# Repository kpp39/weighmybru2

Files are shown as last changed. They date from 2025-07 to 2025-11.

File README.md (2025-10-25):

<p align="center">
WeighMyBru Dashboard
</p>

<p align="center">  <b>The smart coffee scale that doesn't break the bank!<br>https://weighmybru.com</p>
<br>




This project is a smart coffee scale with a webserver hosted on the ESP32-S3.
This scale was designed to be used in conjunction with GaggiMate, but can also be used as a standalone scale. The project is still in a beta phase and is actively being worked on. Please head over to the [Discord](https://discord.gg/HYp4TSEjSf) server for more info. This scale was inspired by [EspressiScale](https://www.espressiscale.com) but with a non-custom PCB approach. The idea is to be low-cost, easily sourcable scale.

<br>
<br>
<p>
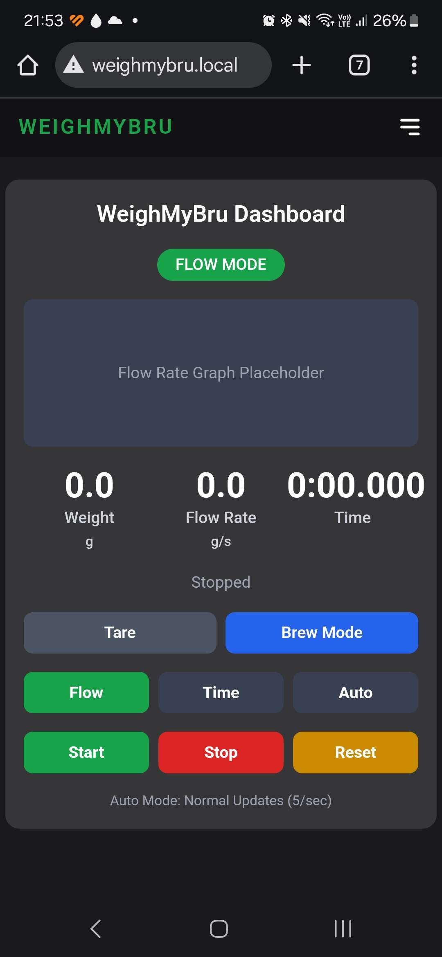
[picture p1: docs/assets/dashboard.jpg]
WeighMyBru Dashboard

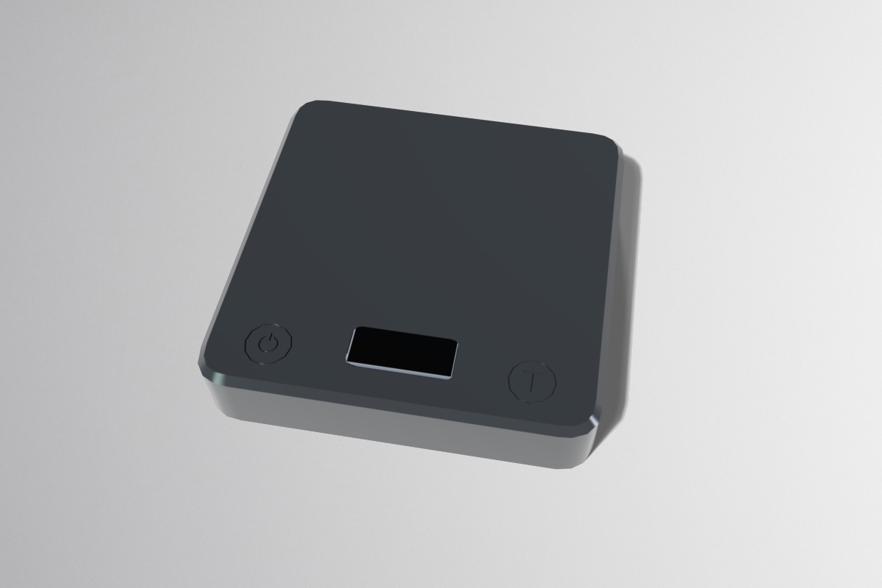
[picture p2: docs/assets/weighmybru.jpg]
WeighMyBru Dashboard

</p>

## Documentation

The documentation, build video guide, flashing software etc. can be found on the website. 

[WeighMyBru Guides](https://weighmybru.com/guides/)

## Features

- Webserver via WiFi
- Bluetooth connectivity to GaggiMate
- Calibration via webserver
- Real-time flowrate display
- Adjustable decimal point readings
- Different modes for to cater for espresso and pour-overs

## GaggiMate

GaggiMate now fully supports WeighMyBru scale.

[GaggiMate](https://github.com/jniebuhr/gaggimate)

## Installation

Installation instructions are currently under development, for now follow the [link](https://031devstudios.github.io/weighmybru-docs/#/installation/flashing) for step-by-step installation instructions. Additionally, a video is available on [YouTube](https://www.youtube.com/watch?v=O5SP40Liuq0)

```
  this project requires VSCode with PlatformIO extension installed
```
## Bill Of Materials (BOM)

| Qty | Item | Amazon Link | Aliexpress Link |
| --- | --- | ---| --- |
|  1  | 500g Mini Loadcell (I-shaped) | https://a.co/d/6kvxZ0H |  |
|  1  | HX711 | https://a.co/d/3KiYRkA |  |
|  1  | ESP32-S3-Supermini Board | https://a.co/d/6289vbS |  |
|  2  | Capacitive Tocuh Pads | https://a.co/d/014di6l |  |
|  1  | 0.91" SSD1306 OLED Display | https://a.co/d/9UClWku |  |
|  1  | 800mAh Li-ion Battery | https://a.co/d/gbr1Yft |  |
|  1  | JST-PH 2.0 Male Connector | https://a.co/d/3BZGuHW |  |
|  1  | Slide Switch | https://a.co/d/9KRqMyF |  |
|  1  | Hookup Wire (Various Colors) | https://a.co/d/1Fs8os9 |  |
|  2  | M3x5x4 Heat Set Inserts | https://a.co/d/bnQD7Iu |  |
|  16 | M1.7x4 Self Tapping Screws | https://a.co/d/1np5Nes |  |
|  4  | M3x12 Button Head Screws | https://a.co/d/iqM3d6E |  |
|  2  | 100K ohm 1% 1/4w resistors | https://a.co/d/3R0YmGM |  |
|  4  | Self-Adhesive Rubber Feet | https://a.co/d/0q9TRmR |  |
|  1  | Double Sided Tape (To hold Battery) | https://a.co/d/gM5SWwH |  |

## Printed Parts (Found in CAD Folder)

| Qty | Item | 
| --- | ---|
|  1  | Bottom* |  
|  1  | Top |
|  1  | ESP32 Clamp |
|  1  | Screen Clamp |
|  4  | M2 Washers (Used for HX711) |

\* Bottom has 2 options - The supported option has engineered supports, while the standard option requires you to slice with your own supports.

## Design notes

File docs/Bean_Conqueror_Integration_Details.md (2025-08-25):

# WeighMyBru - Bean Conqueror Integration Details

## Current BLE Implementation for Bean Conqueror Integration

### Advertising Information
- **Device Name**: `WeighMyBru`
- **Advertising**: Device advertises continuously when not connected

### Service and Characteristic UUIDs
- **Service UUID**: `6E400001-B5A3-F393-E0A9-E50E24DCCA9E`
- **GaggiMate Weight Characteristic UUID**: `6E400002-B5A3-F393-E0A9-E50E24DCCA9E`
  - Properties: READ, NOTIFY, INDICATE
  - Used for: GaggiMate weight data (WeighMyBru protocol format)
- **Command Characteristic UUID**: `6E400003-B5A3-F393-E0A9-E50E24DCCA9E`
  - Properties: WRITE, WRITE_NR, NOTIFY
  - Used for: Receiving commands from both apps (tare, timer control)
- **Bean Conqueror Weight Characteristic UUID**: `6E400004-B5A3-F393-E0A9-E50E24DCCA9E`
  - Properties: READ, NOTIFY, INDICATE
  - Used for: Bean Conqueror weight data (simple float format)

### Required API Functions - Implementation Status

#### ✅ Weight Send
- **Status**: ✅ IMPLEMENTED
- **Frequency**: 50ms interval (20 updates/second)
- **Format**: WeighMyBru protocol with weight data in grams
- **Precision**: Floating point weight values

#### ✅ Taring
- **Status**: ✅ IMPLEMENTED
- **Command Code**: `0x01`
- **Protocol**: Send `[0x03, 0x0A, 0x01, 0x01, 0x00]` to command characteristic
- **Response**: Confirmation message sent back via weight characteristic
- **Function**: Zeros the scale reading

#### ✅ Timer Start
- **Status**: ✅ IMPLEMENTED (NEW)
- **Command Code**: `0x02`
- **Protocol**: Send `[0x03, 0x0A, 0x02, 0x01, 0x00]` to command characteristic
- **Response**: Start confirmation `[0x03, 0x0A, 0x02, 0x01, 0x00]`
- **Function**: Starts the brewing timer on WeighMyBru scale

#### ✅ Timer Stop
- **Status**: ✅ IMPLEMENTED (NEW)
- **Command Code**: `0x03`
- **Protocol**: Send `[0x03, 0x0A, 0x03, 0x01, 0x00]` to command characteristic
- **Response**: Stop confirmation `[0x03, 0x0A, 0x03, 0x01, 0x00]`
- **Function**: Stops the brewing timer on WeighMyBru scale

#### ✅ Timer Reset
- **Status**: ✅ IMPLEMENTED (NEW)
- **Command Code**: `0x04`
- **Protocol**: Send `[0x03, 0x0A, 0x04, 0x01, 0x00]` to command characteristic
- **Response**: Reset confirmation `[0x03, 0x0A, 0x04, 0x01, 0x00]`
- **Function**: Resets the brewing timer to 0:00.000

## Protocol Details

### Command Message Format
```
[Product_ID, Message_Type, Command, Trigger, Reserved]
```
- **Product_ID**: `0x03` (WeighMyBru identifier)
- **Message_Type**: `0x0A` (System command)
- **Command**: Command code (0x01-0x04)
- **Trigger**: `0x01` (Execute command)
- **Reserved**: `0x00` (Future use)

### Weight Data Format
- Sent via weight characteristic notifications
- **Format**: Simple 4-byte float in little-endian byte order  
- **Data**: Weight value directly in grams (e.g., 15.67g)
- **Precision**: Full floating-point precision
- **Update Rate**: Automatic notifications every 50ms when connected
- **Byte Layout**: `[float32_little_endian]` (4 bytes total)

### Connection Behavior
- Automatically starts advertising when disconnected
- Stops advertising when connected
- Supports single client connection
- Automatic reconnection support

## Integration Notes for Bean Conqueror

1. **Discovery**: Look for device named "WeighMyBru" in BLE scan
2. **Connection**: Connect to service UUID `6E400001-B5A3-F393-E0A9-E50E24DCCA9E`
3. **Weight Subscription**: Subscribe to notifications on `6E400004-B5A3-F393-E0A9-E50E24DCCA9E` (Bean Conqueror specific)
4. **Command Sending**: Write commands to `6E400003-B5A3-F393-E0A9-E50E24DCCA9E`
5. **Timer Control**: All timer functions (start/stop/reset) are now available via BLE

### Important: Dual App Support
The WeighMyBru scale now supports **both Bean Conqueror and GaggiMate simultaneously**:

**Bean Conqueror**: 
- Weight data: `6E400004-...` (4-byte float32 little-endian)
- Expected format: Simple float value in grams

**GaggiMate**: 
- Weight data: `6E400002-...` (20-byte WeighMyBru protocol)
- Expected format: Full protocol with headers and checksums

**Commands**: Both apps share `6E400003-...` for tare and timer commands

## Technical Specifications

- **Platform**: ESP32-S3
- **BLE Stack**: ESP32 Arduino BLE library
- **Update Rate**: 20Hz (50ms intervals)
- **Weight Range**: 0-5000g (depending on load cell)
- **Precision**: 0.1g
- **Timer Precision**: Millisecond accuracy
- **Connection**: Single client BLE connection
- **Power**: Battery operated with monitoring

## Example Usage

```javascript
// Connect to WeighMyBru
const device = await navigator.bluetooth.requestDevice({
  filters: [{name: 'WeighMyBru'}],
  optionalServices: ['6E400001-B5A3-F393-E0A9-E50E24DCCA9E']
});

// Subscribe to weight notifications
const weightChar = await service.getCharacteristic('6E400002-B5A3-F393-E0A9-E50E24DCCA9E');
await weightChar.startNotifications();

// Send tare command
const commandChar = await service.getCharacteristic('6E400003-B5A3-F393-E0A9-E50E24DCCA9E');
await commandChar.writeValue(new Uint8Array([0x03, 0x0A, 0x01, 0x01, 0x00]));

// Send timer start command
await commandChar.writeValue(new Uint8Array([0x03, 0x0A, 0x02, 0x01, 0x00]));
```

## Changes Made for Bean Conqueror Integration

### New Features Added:
1. **Timer Control API**: Added BLE commands for start/stop/reset timer
2. **Command Processing**: Enhanced message processing to handle timer commands
3. **Display Integration**: Linked BLE timer commands to physical display timer
4. **Confirmation Messages**: Added response confirmations for all commands

### Files Modified:
- `include/BluetoothScale.h` - Added timer command enums and methods
- `src/BluetoothScale.cpp` - Implemented timer command handling
- `src/main.cpp` - Added display reference for timer control

All required API functions for Bean Conqueror integration are now implemented and ready for testing.

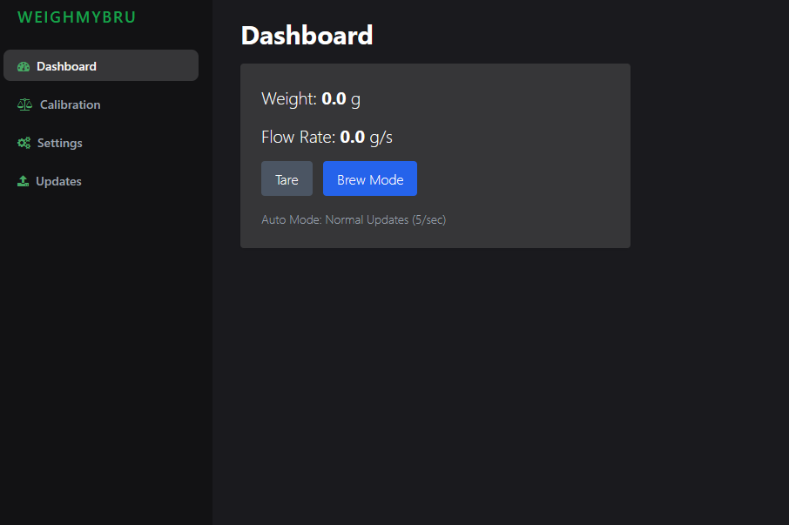
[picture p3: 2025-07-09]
docs/assets/dashboard.png

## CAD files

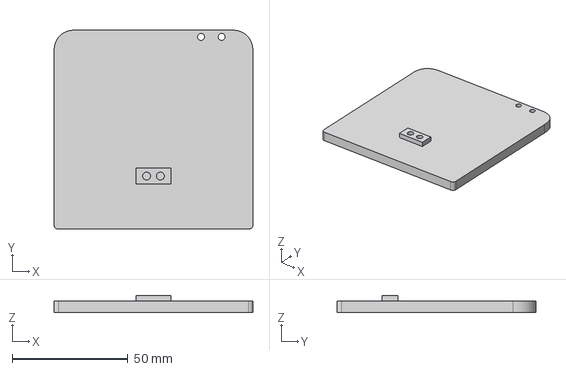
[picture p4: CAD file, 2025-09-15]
cad/step/WeighMyBru² - Bottom Supported.step
86.0 x 86.0 x 7.50 mm

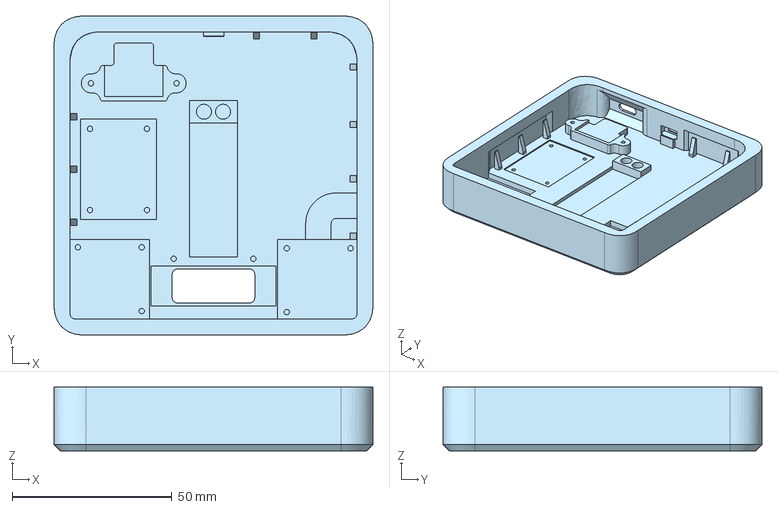
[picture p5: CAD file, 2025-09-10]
cad/step/WeighMyBru² - Top.step
100.0 x 100.0 x 20.0 mm

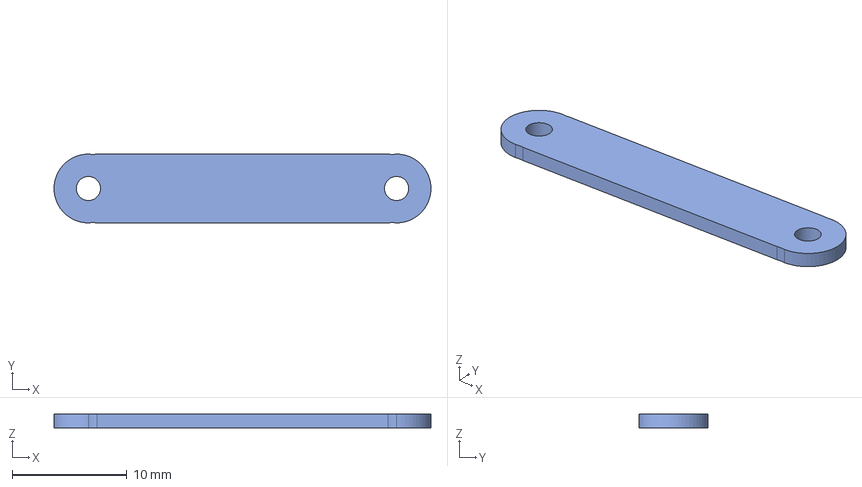
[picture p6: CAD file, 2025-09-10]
cad/step/WeighMyBru² - ESP32 Clamp.step
32.8 x 6.00 x 1.20 mm

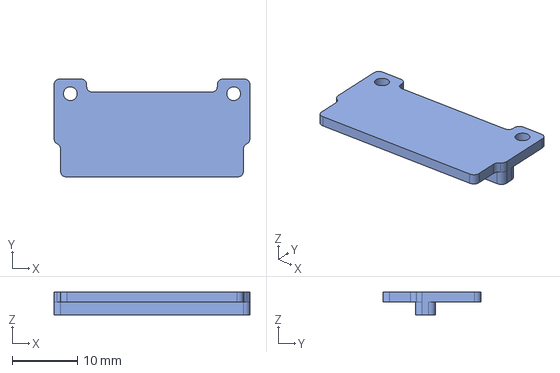
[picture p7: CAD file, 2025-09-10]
cad/step/WeighMyBru² - Screen Clamp.step
30.0 x 15.0 x 3.50 mm

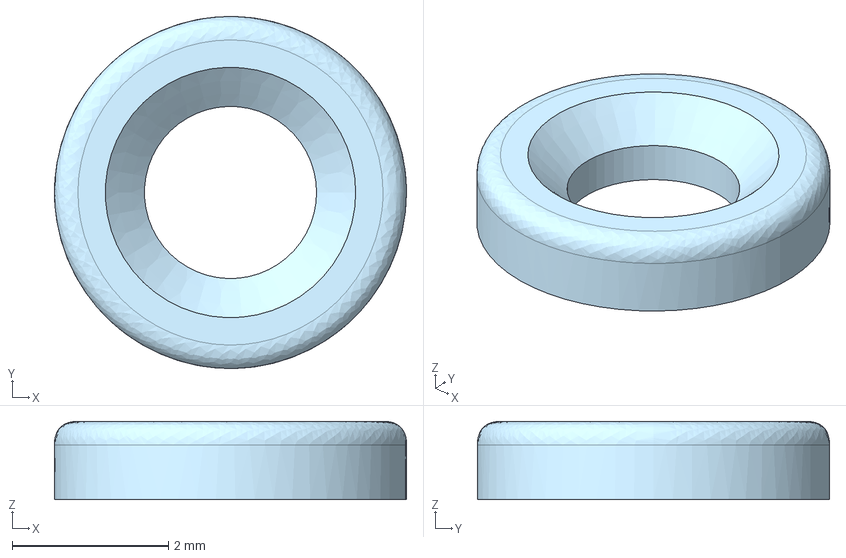
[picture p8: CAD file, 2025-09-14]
cad/step/WeighMyBru² - M2 Washer.step
4.50 x 4.50 x 1.00 mm

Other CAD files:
cad/step/WeighMyBru² - Bottom.step
cad/3mf/WeighMyBru² - Bottom Supported.3mf
cad/3mf/WeighMyBru² - Bottom.3mf
cad/3mf/WeighMyBru² - ESP32 Clamp.3mf
cad/3mf/WeighMyBru² - M2 Washer.3mf
cad/3mf/WeighMyBru² - Screen Clamp.3mf
cad/3mf/WeighMyBru² - Top.3mf

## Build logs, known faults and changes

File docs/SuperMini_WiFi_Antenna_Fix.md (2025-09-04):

# ESP32-S3 SuperMini WiFi Antenna Fix

## Problem Description

Some ESP32-S3 SuperMini development boards have a hardware design issue where:
- WiFi only works when physically touching the antenna
- Poor WiFi connectivity or complete failure to connect
- Issues are more pronounced at distance from the router

## Root Cause

The issue is caused by:
1. **Poor antenna design** - inadequate antenna keep-out clearance
2. **GPIO interference** - GPIO21 can interfere with antenna performance
3. **Low default TX power** - insufficient power for poor antenna design

## Software Solution

This fix implements maximum WiFi transmission power to compensate for the antenna issues:

### Implementation Details

```cpp
// Enable maximum TX power at both framework levels
WiFi.setTxPower(WIFI_POWER_19_5dBm);        // Arduino framework: 19.5dBm
esp_wifi_set_max_tx_power(40);              // ESP-IDF level: 10dBm (40 = 4 * 10dBm)
```

### Configuration

The fix can be enabled/disabled in `WiFiManager.h`:

```cpp
#define ENABLE_SUPERMINI_ANTENNA_FIX true    // Enable for problematic boards
#define ENABLE_SUPERMINI_ANTENNA_FIX false   // Disable for normal boards
```

### When to Use

**Enable this fix if:**
- WiFi only works when touching the antenna
- Poor WiFi connectivity on SuperMini boards
- Connection fails at normal distances from router
- Board has insufficient antenna keep-out clearance

**Disable this fix if:**
- Using high-quality boards with proper antenna design
- Want to minimize power consumption
- Board already has reliable WiFi connectivity

## Hardware Solutions (Alternative)

For permanent hardware fixes:

1. **GPIO21 Issue**: Remove LED or connections on GPIO21
2. **External Antenna**: Add u.FL connector and external antenna
3. **Better Boards**: Use boards with proper antenna keep-out design

## References

- [ESP32 Forum Discussion](https://esp32.com/viewtopic.php?t=41895)
- [Related GPIO21 Issue](http://esp32.io/viewtopic.php?f=19&t=42069)

## Technical Notes

- Power settings are reapplied after WiFi mode switches
- Compatible with BLE coexistence (WiFi sleep mode maintained)
- Minimal performance impact on properly designed boards
- Automatic fallback if ESP-IDF functions unavailable

## Testing

Test effectiveness by:
1. Enable fix and upload firmware
2. Test WiFi connectivity without touching antenna
3. Check connection stability at various distances
4. Monitor serial output for power setting confirmations

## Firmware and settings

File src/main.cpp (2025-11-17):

#include <WiFi.h>
#include "WebServer.h"
#include "WebServer.h"
#include <ESPAsyncWebServer.h>
#include <LittleFS.h>
#include <ESPmDNS.h>
#include <esp_sleep.h>
#include "Scale.h"
#include "WiFiManager.h"
#include "FlowRate.h"
#include "Calibration.h"
#include "BluetoothScale.h"
#include "TouchSensor.h"
#include "Display.h"
#include "PowerManager.h"
#include "BatteryMonitor.h"
#include <FreeRTOS.h>
#include <esp_pm.h>


// Pins and calibration
uint8_t dataPin = 5;   // HX711 Data pin (moved from 12)
uint8_t clockPin = 6;  // HX711 Clock pin (moved from 11)
uint8_t touchPin = 4;  // T0 - Confirmed working touch pin for tare
uint8_t sleepTouchPin = 3;  // GPIO3 - Digital touch sensor for sleep functionality
uint8_t batteryPin = 7;    // GPIO7 - Battery voltage monitoring (ADC1_CH6) - Safe GPIO
uint8_t sdaPin = 8;    // I2C Data pin for display (moved from 5)
uint8_t sclPin = 9;    // I2C Clock pin for display (moved from 6)
float calibrationFactor = 4195.712891;
Scale scale(dataPin, clockPin, calibrationFactor);
FlowRate flowRate;
BluetoothScale bluetoothScale;
TouchSensor touchSensor(touchPin, &scale);
Display oledDisplay(sdaPin, sclPin, &scale, &flowRate);
PowerManager powerManager(sleepTouchPin, &oledDisplay);
BatteryMonitor batteryMonitor(batteryPin);
void uiUpdate(void * parameter){
  TickType_t lastTick = xTaskGetTickCount();
  for(;;){
    touchSensor.update();
    powerManager.update();
    batteryMonitor.update();
    oledDisplay.update();
    xTaskDelayUntil(&lastTick, 25 / portTICK_PERIOD_MS);
  }
}



void weightUpdate(void * parameter){
  TickType_t lastTick = xTaskGetTickCount();
  for(;;){
    float weight = scale.getWeight();
    flowRate.update(weight);
    xTaskDelayUntil(&lastTick, 50 / portTICK_PERIOD_MS);
  }
}
void bleUpdate(void * parameter){
  TickType_t lastTick = xTaskGetTickCount();
  for(;;){
    bluetoothScale.update();
    xTaskDelayUntil(&lastTick, 50 / portTICK_PERIOD_MS);
  }
}


void TaskLog(void *pvParameters) {
  static const int statsBufferSize = 1024;
  static char statsBuffer[statsBufferSize];
  
  static const int listBufferSize = 1024;
  static char listBuffer[listBufferSize];
  static const int locksBufferSize = 2048;
  // char* locksBuffer = (char*) pvPortMalloc(locksBufferSize);
  // if (locksBuffer == NULL) {
  //   Serial.println("Не удалось выделить память");
  // }
  // FILE* mem_file = fmemopen(locksBuffer, locksBufferSize, "w");
  // if (mem_file == NULL) {
  //   Serial.println("Не удалось создать вирт.файл");
  //   vPortFree(locksBuffer);
  // }
  while (true) {
//     // xSemaphoreTake(SerialMutex, portMAX_DELAY);
    Serial.println("\n============ Task Stats ============");
    
    // Get runtime stats for CPU usage
    // This requires configGENERATE_RUN_TIME_STATS to be enabled
        vTaskGetRunTimeStats(statsBuffer);
        Serial.println("Run Time Stats:");
        Serial.println(statsBuffer);
        //get locks
        Serial.println("Locks List:");
        char* locksBuffer = (char*) pvPortMalloc(locksBufferSize);
        if (locksBuffer == NULL) {
          Serial.println("Не удалось выделить память");
        } else {
          FILE* mem_file = fmemopen(locksBuffer, locksBufferSize, "w");
          if (mem_file == NULL) {
            Serial.println("Не удалось создать вирт.файл");
            vPortFree(locksBuffer);
          } else {
            esp_pm_dump_locks(mem_file);
            Serial.println(locksBuffer);
            Serial.println("=====================================");
            fclose(mem_file);
            vPortFree(locksBuffer);            
          }
        }
        // Get task list with state, priority, stack, and task number
        // Note: vTaskList output depends on configuration and may not include core affinities by default
        vTaskList(listBuffer);
        Serial.println("Task List:");
        Serial.println(listBuffer);
        
        Serial.println("=====================================");
        //xSemaphoreGive(SerialMutex);
        vTaskDelay(5000 / portTICK_PERIOD_MS);

    }
} 
void setup() {
  esp_pm_config_t pm_config = {
      .max_freq_mhz = 80, // Maximum CPU frequency when needed
      .min_freq_mhz = 5,  // Minimum CPU frequency when idle
      // .light_sleep_enable = false // Enable automatic light sleep
      .light_sleep_enable = true // Enable automatic light sleep
  };
  
  Serial.begin(115200);
  // Serial.begin(921600);
  
  // Link scale and flow rate for tare operation coordination
  scale.setFlowRatePtr(&flowRate);
  
  // Check for factory reset request (hold touch pin during boot)
  pinMode(touchPin, INPUT_PULLDOWN);
  if (digitalRead(touchPin) == HIGH) {
    Serial.println("FACTORY RESET: Touch pin held during boot - clearing WiFi credentials");
    clearWiFiCredentials();
    delay(1000);
  }
  
  // CRITICAL: Initialize BLE FIRST before WiFi to prevent radio conflicts
  Serial.println("Initializing BLE FIRST for GaggiMate compatibility...");
  Serial.printf("Free heap before BLE init: %u bytes\n", ESP.getFreeHeap());
  Serial.printf("Free PSRAM before BLE init: %u bytes\n", ESP.getFreePsram());
  
  try {
    bluetoothScale.begin();  // Initialize BLE without scale reference
    Serial.println("BLE initialized successfully - GaggiMate should be able to connect");
    Serial.printf("Free heap after BLE init: %u bytes\n", ESP.getFreeHeap());
    Serial.printf("Free PSRAM after BLE init: %u bytes\n", ESP.getFreePsram());
  } catch (...) {
    Serial.println("BLE initialization failed - continuing without Bluetooth");
    Serial.printf("Free heap after BLE fail: %u bytes\n", ESP.getFreeHeap());
  }
  
  // Initialize display with error handling - don't block if display fails
  Serial.println("Initializing display...");
  bool displayAvailable = oledDisplay.begin();
  
  if (!displayAvailable) {
    Serial.println("WARNING: Display initialization failed!");
    Serial.println("System will continue in headless mode without display.");
    Serial.println("All functionality remains available via web interface.");
  } else {
    Serial.println("Display initialized - ready for visual feedback");
  }
  
  // Check wake-up reason and show appropriate message
  esp_sleep_wakeup_cause_t wakeup_reason = esp_sleep_get_wakeup_cause();
  switch(wakeup_reason) {
    case ESP_SLEEP_WAKEUP_EXT0:
      Serial.println("Wakeup caused by external signal (touch sensor)");
      // Show the same starting message as normal boot for consistency
      delay(1500);
      break;
    case ESP_SLEEP_WAKEUP_EXT1:
      Serial.println("Wakeup caused by external signal using RTC_CNTL");
      break;
    case ESP_SLEEP_WAKEUP_TIMER:
      Serial.println("Wakeup caused by timer");
      break;
    case ESP_SLEEP_WAKEUP_TOUCHPAD:
      Serial.println("Wakeup caused by touchpad");
      break;
    default:
      Serial.println("Wakeup was not caused by deep sleep: " + String(wakeup_reason));
      // For normal startup, the begin() method already shows a startup message
      delay(1000);
      break;
  }
  //Wait for BLE to finish intitalizing before starting WiFi
  delay(1500); 
  
  // ALWAYS enable WiFi power management for optimal battery life
  // This works regardless of WiFi mode (STA/AP/OFF) and should be set early
  WiFi.setSleep(true);
  Serial.println("WiFi power management enabled for battery optimization");
  
  setupWiFi();

  // Wait for WiFi to fully stabilize after BLE is already running
  delay(1500);
  Serial.printf("Version: %s\n", ESP.getSdkVersion());
  // Initialize scale with error handling - don't block web server if HX711 fails
  Serial.println("Initializing scale...");
  if (!scale.begin()) {
    Serial.println("WARNING: Scale (HX711) initialization failed!");
    Serial.println("Web server will continue to run, but scale readings will not be available.");
    Serial.println("Check HX711 wiring and connections.");
  } else {
    Serial.println("Scale initialized successfully");
    // Now that scale is ready, set the reference in BluetoothScale
    bluetoothScale.setScale(&scale);
  }
  
  // BLE was initialized earlier - no need to initialize again
  // bluetoothScale.begin(&scale);
  
  // Set bluetooth reference in display for status indicator (if display available)
  if (oledDisplay.isConnected()) {
    oledDisplay.setBluetoothScale(&bluetoothScale);
  }
  
  // Set display reference in bluetooth for timer control
  bluetoothScale.setDisplay(&oledDisplay);
  
  // Set power manager reference in display for timer state synchronization (if display available)
  if (oledDisplay.isConnected()) {
    oledDisplay.setPowerManager(&powerManager);
  }
  
  // Set battery monitor reference in display for battery status (if display available)
  if (oledDisplay.isConnected()) {
    oledDisplay.setBatteryMonitor(&batteryMonitor);
  }

  // Initialize touch sensor
  touchSensor.begin();

  // Initialize power manager
  powerManager.begin();

  // Initialize battery monitor
  batteryMonitor.begin();

  // Show IP addresses and welcome message if display is available
  delay(100); // Small delay to ensure WiFi is fully initialized
  if (oledDisplay.isConnected()) {
    oledDisplay.showIPAddresses();
  }

  // Link display to touch sensor for tare feedback (if display available)
  if (oledDisplay.isConnected()) {
    touchSensor.setDisplay(&oledDisplay);
  }
  
  // Link flow rate to touch sensor for averaging reset on tare
  touchSensor.setFlowRate(&flowRate);

  setupWebServer(scale, flowRate, bluetoothScale, oledDisplay, batteryMonitor);
  xTaskCreate (
    weightUpdate,
    "Weight upd",
    10000,
    NULL,
    1,
    NULL
  );
  xTaskCreate (
    bleUpdate,
    "Update Bt",
    10000,
    NULL,
    1,
    NULL
  );
  
  xTaskCreate (
    printWiFiStatus,
    "WiFi state",
    10000,
    NULL,
    1,
    NULL
  );
  xTaskCreate (
    maintainWiFi,
    "WiFi Health",
    10000,
    NULL,
    1,
    NULL
  );
   xTaskCreate (
    uiUpdate,
    "UI update",
    10000,
    NULL,
    1,
    NULL
  );
  // xTaskCreate(
  //       TaskLog,     // Функция задачи
  //       "Log",       // Имя задачи
  //       10000,        // Увеличили размер стека для доп. вычислений
  //       NULL,        // Параметры задачи
  //       1,           // Приоритет задачи
  //       NULL
  //   );

  ESP_ERROR_CHECK(esp_pm_configure(&pm_config));
}

// void loop() {}
// void loop() {vTaskDelay(100);}
// void loop() {vTaskDelay(1000);vTaskDelete(NULL);}
void loop() {vTaskDelete(NULL);}

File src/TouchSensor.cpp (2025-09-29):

#include "TouchSensor.h"
#include "Scale.h"
#include "Display.h"
#include "FlowRate.h"
#include "WiFiManager.h"

TouchSensor::TouchSensor(uint8_t touchPin, Scale* scale) 
    : touchPin(touchPin), scalePtr(scale), displayPtr(nullptr), flowRatePtr(nullptr), touchThreshold(30000), 
      lastTouchState(false), lastTouchTime(0), touchStartTime(0), debounceDelay(200),
      longPressDetected(false), delayedTarePending(false), delayedTareTime(0) {
}

void TouchSensor::begin() {
    // Set up the pin as digital input with pull-down resistor for the touch sensor module
    // This prevents false triggers when no touch sensor is connected
    pinMode(touchPin, INPUT_PULLDOWN);
    Serial.println("Digital touch sensor initialized on pin " + String(touchPin) + " with pull-down resistor");
}

void TouchSensor::update() {
    bool currentTouchState = isTouched();
    unsigned long currentTime = millis();
    
    // Check for touch state change with debouncing
    if (currentTouchState != lastTouchState) {
        if (currentTime - lastTouchTime > debounceDelay) {
            if (currentTouchState) {
                // Touch started - record start time
                touchStartTime = currentTime;
                longPressDetected = false;
                Serial.println("Touch started");
            } else {
                // Touch ended
                unsigned long pressDuration = currentTime - touchStartTime;
                
                if (!longPressDetected) {
                    if (pressDuration >= WIFI_TOGGLE_DURATION) {
                        // Very long press (5+ seconds) - WiFi toggle
                        handleWiFiToggle();
                        Serial.println("Very long press detected - WiFi toggle");
                    } else if (pressDuration >= 500) {
                        // Medium press (500ms+) - Status page toggle
                        handleStatusPageToggle();
                        Serial.println("Medium press detected - status page toggle");
                    } else {
                        // Short press - Tare
                        scheduleDelayedTare();
                        Serial.println("Short press detected - tare");
                    }
                }
                longPressDetected = false;
                Serial.println("Touch ended");
            }
            lastTouchState = currentTouchState;
            lastTouchTime = currentTime;
        }
    }
    
    // Check for very long press (WiFi toggle) while touch is still active
    if (currentTouchState && !longPressDetected && touchStartTime > 0) {
        if (currentTime - touchStartTime >= WIFI_TOGGLE_DURATION) {
            longPressDetected = true;
            handleWiFiToggle();
            Serial.println("Very long press detected (during hold) - WiFi toggle");
        }
    }
    
    // Check for pending delayed tare
    checkDelayedTare();
}

void TouchSensor::setTouchThreshold(uint16_t threshold) {
    touchThreshold = threshold;
    Serial.println("Touch threshold set to: " + String(touchThreshold));
}

uint16_t TouchSensor::getTouchValue() {
    // For digital touch sensor modules, return the digital state as 0 or 1
    return digitalRead(touchPin) ? 1 : 0;
}

bool TouchSensor::isTouched() {
    // For digital touch sensor modules, check if the pin is HIGH
    // Most touch sensor modules output HIGH when touched
    bool touched = digitalRead(touchPin) == HIGH;
    
    // Debug: log unexpected HIGH readings when no sensor should be connected
    static unsigned long lastDebugTime = 0;
    if (touched && millis() - lastDebugTime > 5000) { // Log every 5 seconds max
        Serial.println("DEBUG: Touch pin GPIO" + String(touchPin) + " reading HIGH - check for floating pin or connected sensor");
        lastDebugTime = millis();
    }
    
    return touched;
}

void TouchSensor::setDisplay(Display* display) {
    displayPtr = display;
}

void TouchSensor::setFlowRate(FlowRate* flowRate) {
    flowRatePtr = flowRate;
}

void TouchSensor::handleTouch() {
    if (scalePtr != nullptr) {
        Serial.println("Touch detected! Taring scale...");
        
        // Show tare message on display if available
        if (displayPtr != nullptr) {
            displayPtr->showTaringMessage();
        }
        
        scalePtr->tare();
        Serial.println("Scale tared successfully");
        
        // Reset timer when manual tare is pressed
        if (displayPtr != nullptr) {
            displayPtr->resetTimer();
            Serial.println("Timer reset with manual tare");
        }
        
        // Reset flow rate averaging for fresh brew
        if (flowRatePtr != nullptr) {
            flowRatePtr->resetTimerAveraging();
            Serial.println("Flow rate averaging reset for fresh brew");
        }
        
        // Show completion message on display if available
        if (displayPtr != nullptr) {
            displayPtr->showTaredMessage();
        }
    } else {
        Serial.println("Error: Scale pointer is null");
    }
}

void TouchSensor::scheduleDelayedTare() {
    Serial.println("Touch detected - showing taring message immediately");
    
    // Show taring message immediately for better user feedback
    if (displayPtr != nullptr) {
        displayPtr->showTaringMessage();
        Serial.println("Taring message displayed");
    }
    
    Serial.println("Scheduling delayed tare in 1.5 seconds...");
    delayedTarePending = true;
    delayedTareTime = millis() + TARE_DELAY;
}

void TouchSensor::checkDelayedTare() {
    if (delayedTarePending && millis() >= delayedTareTime) {
        Serial.println("Executing delayed tare operation");
        delayedTarePending = false;
        
        // Perform the actual tare operation without showing message again
        if (scalePtr != nullptr) {
            scalePtr->tare();
            Serial.println("Scale tared successfully");
            
            // Reset timer when manual tare is pressed
            if (displayPtr != nullptr) {
                displayPtr->resetTimer();
                Serial.println("Timer reset with manual tare");
            }
            
            // Reset flow rate averaging for fresh brew
            if (flowRatePtr != nullptr) {
                flowRatePtr->resetTimerAveraging();
                Serial.println("Flow rate averaging reset for fresh brew");
            }
            
            // Show completion message on display if available
            if (displayPtr != nullptr) {
                displayPtr->showTaredMessage();
            }
        } else {
            Serial.println("Error: Scale pointer is null");
        }
    }
}

void TouchSensor::handleStatusPageToggle() {
    Serial.println("Medium press detected - toggling status page");
    
    if (displayPtr != nullptr) {
        displayPtr->toggleStatusPage();
    } else {
        Serial.println("Error: Display pointer is null");
    }
}
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

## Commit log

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2025-08-05 Added error handling for HX711
    [Display.cpp, Scale.cpp, WebServer.cpp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]
2025-08-05 Added support and indicators for runnnig in headless mode, without display, and improved error handling for no HX711 detection.
    [BluetoothScale.cpp, PowerManager.cpp, Scale.cpp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]
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2025-08-06 Fixed some filtering issues
    [Scale.cpp]
2025-08-06 Fixed taring issues affecting the weights after taring
    [TouchSensor.cpp]
2025-08-13 Kinda fixed AUTO mode, still might have bugs
    [Display.cpp, FlowRate.cpp, Scale.cpp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]
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2025-08-18 Fix WiFi issue: Move battery pin from GPIO1 to GPIO7
    - GPIO1 is a strapping pin that interferes with WiFi initialization
    - GPIO7 (ADC1_CH6) is safer and provides same ADC functionality
    - This should resolve AP mode and STA connection issues
    [main.cpp]
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2025-08-18 feat: Complete battery monitoring system with calibration and mobile UI
    - Add comprehensive BatteryMonitor class with Li-ion voltage management
    - Implement 100kΩ voltage divider on GPIO7 with ADC calibration
    - Add battery calibration API endpoints (GET/POST) with persistent storage
    - Create user-friendly calibration interface in web dashboard
    - Add phone-style 4-segment battery indicator in top-right corner
    - Fix WiFi/BLE coexistence issue (WiFi sleep enabled for dual radio)
    - Update dashboard title from 'WeighMyBru Dashboard' to 'Dashboard'
    - Add real-time battery status with color-coded indicators
    - Support voltage range 2.9V-4.2V with smart percentage calculation
    - Include battery debug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
    [BatteryMonitor.cpp, BatteryMonitor.h, WebServer.cpp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]
2025-08-18 Implement comprehensive battery monitoring system
    Features added:
    - Complete BatteryMonitor class with Li-ion voltage management
    - GPIO7 ADC integration with 100kΩ voltage divider support
    - 4-segment OLED battery indicator with critical battery flashing
    - Web-based battery calibration interface on /calibration page
    - Battery status API endpoints (GET/POST /api/battery)
    - Mobile-responsive dashboard with phone-style battery indicator
    - WiFi/BLE coexistence fixes with WiFi sleep mode
    - Clean OLED display with pixel-art Bluetooth icon
    - Persistent calibration storage in EEPROM
    - Critical battery warning with solid white flashing animation
    Hardware:
    - Battery monitoring on GPIO7 with voltage d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
    [Display.cpp]
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2025-08-23 Implement Bean Conqueror BLE integration
    - Add timer control commands via BLE (start/stop/reset)
    - Enhanced command processing with proper protocol handling
    - Add display reference to BluetoothScale for timer control
    - Add comprehensive documentation for Lars
    - All required API functions now implemented:
    * Weight send (existing)
    * Taring (enhanced)
    * Timer start/stop/reset (new)
    Ready for Bean Conqueror integration testing.
    [BluetoothScale.cpp, main.cpp]
2025-08-23 Fix Bean Conqueror integration issues
    - Fix timer pause/resume functionality: Timer now properly resumes from paused state across BLE and web interfaces
    - Fix weight data format: Change from WeighMyBru protocol to simple 4-byte float32 little-endian format expected by Bean Conqueror
    - Update documentation with correct weight format specifications
    Both timer control and weight display now work correctly with Bean Conqueror app
    [BluetoothScale.cpp, Display.cpp]
2025-08-25 Implement dual BLE characteristics for Bean Conqueror and GaggiMate compatibility
    - Add separate weight characteristics for each app format
    - GaggiMate: 6E400002 (WeighMyBru protocol, 20 bytes)
    - Bean Conqueror: 6E400004 (simple float32, 4 bytes)
    - Maintain backward compatibility for GaggiMate
    - Add error handling to prevent crashes
    - Update documentation with correct UUID mapping
    [BluetoothScale.cpp]
2025-08-25 Fix boot loop and BLE message processing issues
    - Add BLE power reduction to prevent boot loops on battery power
    - Filter incoming messages to only process WeighMyBru protocol (Product 0x03)
    - Ignore GaggiMate's unknown messages that were causing infinite loops
    - Reduce BLE TX power levels for better battery stability
    - Add error handling for message validation
    This should resolve both the boot loop when unplugged and the repetitive BLE message spam.
    [BluetoothScale.cpp]
2025-08-25 Fix under-voltage boot issue with lower-power BLE initialization
    - Reduce BLE TX power to minimum (ESP_PWR_LVL_N12) during initialization
    - Add global BLE power reduction during boot to reduce current draw
    - Add memory monitoring for debugging
    - Add power settling delay between BLE init steps
    This should allow booting on batteries with lower voltage (3.99V) that were causing boot loops due to voltage sag during high-current BLE initialization.
    [BluetoothScale.cpp, main.cpp]
2025-08-25 Fix BLE connectivity issues for dual app support
    - Increase BLE power from -12dBm to -3dBm for better connectivity range
    - Accept messages from both GaggiMate (Product 0x02) and WeighMyBru (Product 0x03)
    - Maintain power optimization during boot to prevent under-voltage issues
    - Enable simultaneous Bean Conqueror and GaggiMate compatibility
    This resolves the connectivity issues where GaggiMate couldn't read weights
    after the under-voltage boot fix implementation.
    [BluetoothScale.cpp]
2025-08-25 Optimize battery voltage scale for ESP32 operation
    - Adjust voltage thresholds for 700mAh/1200mAh Li-ion batteries
    - Set reliable boot threshold at 4.0V (75% instead of old ~95%)
    - Update BATTERY_GOOD from 3.8V to 4.0V for ESP32 stability
    - Update BATTERY_CRITICAL from 3.0V to 3.2V (may not boot reliably)
    - Update BATTERY_EMPTY from 2.9V to 3.0V (protection threshold)
    - Add ESP32-specific status descriptions with boot reliability info
    This provides more accurate battery percentages that reflect actual
    ESP32 operating requirements under BLE load conditions.
    [BatteryMonitor.cpp, BatteryMonitor.h]
2025-08-25 Set conservative battery empty threshold at 3.5V
    - Change BATTERY_EMPTY from 3.0V to 3.5V for safer operation
    - Change BATTERY_CRITICAL from 3.2V to 3.5V (charge immediately)
    - Provides better safety buffer above protection circuit threshold
    - Ensures user gets early warning before ESP32 becomes unreliable
    This prevents users from running the battery too low and gives
    more time to charge before encountering boot issues.
    [BatteryMonitor.cpp, BatteryMonitor.h]
2025-08-25 Fix display layout: swap timer and flow rate positions
    - Move timer to bottom left (fixed position)
    - Move flow rate to bottom right (fixed position)
    - Remove Bluetooth adjustment for flow rate positioning
    - Flow rate no longer shifts when Bluetooth connects/disconnects
    This resolves the issue where flow rate would move left when the
    Bluetooth indicator appeared, even though they are in different
    areas of the display (top vs bottom).
    [Display.cpp]
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2025-08-27 Optimize WiFi power consumption with smart mode switching
    Key improvements:
    - Prioritize STA mode connection when credentials exist for lower power consumption
    - Only fallback to AP mode if no credentials stored or STA connection fails
    - Stop AP broadcasting once STA successfully connects (significant power savings)
    - Immediate connection attempt when new credentials entered (no reboot required)
    - Smart fallback to AP mode if STA connection fails during credential entry
    - Enhanced user feedback with JSON responses showing connection status and IP
    Technical changes:
    - Modified setupWiFi() to try STA first, only start AP as fallback
    - Added attemptSTAConnection() for immediate connection with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
    [WebServer.cpp, WiFiManager.cpp, main.cpp]
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2025-08-27 Fix WiFi maintenance breaking STA-only mode + Status page layout improvements
    Critical WiFi Fix:
    - Fixed maintainWiFi() function incorrectly switching from STA back to AP mode
    - Old logic assumed dual AP+STA mode and 'restored' AP when seeing STA-only mode
    - New logic respects STA-only mode for power optimization
    - Only switches to AP mode if STA connection actually fails
    - Intelligent STA reconnection attempts before AP fallback
    - Maintains intended power-saving behavior
    Status Page Layout:
    - Removed 'BAT:' prefix from battery percentage (cleaner display)
    - Moved IP address to bottom of display (y=24 on 32-pixel screen)
    - Better space utilization and visual hierarchy
    - Battery shows as '85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
    [Display.cpp, WiFiManager.cpp]
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2025-08-27 Implement custom weight display with compact decimal point
    Problem solved:
    - Weight display with 3 digits (e.g., 100.5g) was crashing into timer/flow rate on right
    - Large size-3 decimal point was taking too much horizontal space
    - Layout became cramped and unreadable at higher weights
    Solution implemented:
    - Custom weight rendering using mixed text sizes for optimal space usage
    - Integer part: Size 3 text for prominence (e.g., '100')
    - Decimal point: Size 1 text positioned at baseline for minimal footprint
    - Decimal digit: Size 2 text for good readability (e.g., '5')
    - Negative sign: Size 3 text when needed (e.g., '-12')
    Technical details:
    - Split weight into integer and decimal parts pro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
    [Display.cpp]
2025-08-27 Fix message timing and optimize user experience
    Message duration improvements:
    - Startup 'WeighMyBru Ready' message reduced from 3 seconds to 1 second for faster boot
    - 'Scale Tared!' message reduced from 2 seconds to 1 second for quicker feedback
    Taring sequence bug fix:
    - Fixed broken taring message timing that caused premature display transitions
    - 'Taring . . .' message now properly displays for full 2 seconds during tare process
    - 'Scale Tared!' message uses specific 1-second duration override
    - Eliminated brief return to main display between taring messages
    Technical implementation:
    - Kept default messageDuration at 2000ms for taring process stability
    - Added messageDuration override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
    [Display.cpp]
2025-08-27 Fix taring message sequence bug - proper duration handling
    Problem resolved:
    - First tare worked correctly but subsequent tares were broken
    - showTaredMessage() was permanently modifying messageDuration from 2000ms to 1000ms
    - Caused 'Taring . . .' message on subsequent tares to show for only 1 second
    - Result: premature return to main display, then 'Scale Tared!' appeared
    Root cause:
    - messageDuration class member was being modified and not restored
    - Affected all subsequent message timing, not just tared messages
    - Removed permanent messageDuration modification from showTaredMessage()
    - Added smart duration logic in timeout check using effectiveDuration
    - Detects 'T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
    [Display.cpp]
2025-08-28 Fix BLE stability and weight display rounding issues
    BLE Stability Improvements:
    - Increase BLE transmission power from -3dBm to 0dBm for stronger signal
    - Optimize main loop delay from 5ms to 25ms to reduce system overload
    - Throttle BLE updates from every 5ms to every 50ms (200Hz → 20Hz)
    - Reduce weight reading frequency from 10ms to 20ms (100Hz → 50Hz)
    - Maintains excellent responsiveness while reducing BLE interference
    Weight Display Bug Fix:
    - Fix decimal rounding carry-over issue (4.95g showing as '4.10' instead of '5.0')
    - Add proper carry-over handling when decimal part rounds to 10 or higher
    - Ensures correct progression: 4.7 → 4.8 → 4.9 → 5.0
    Root Cause Analysis:
    - BLE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
    [BluetoothScale.cpp, Display.cpp, main.cpp]
2025-08-28 Implement compact decimal points and T/F labels for timer and flow rate
    Display Improvements:
    - Apply compact decimal point rendering to timer and flow rate (matching weight display)
    - Add 'T' and 'F' labels for clear identification of timer vs flow rate
    - Position labels at far right edge for consistent alignment regardless of number size
    Compact Decimal Implementation:
    - Timer: Size 2 integer + Size 1 decimal point + Size 1 decimal digit
    - Flow rate: Size 2 integer + Size 1 decimal point + Size 1 decimal digit
    - Proper carry-over handling (e.g., 12.95 → 13.0, not 12.10)
    - Significant space savings with smaller decimal points
    Label Positioning System:
    - 'T' label: Fixed at far right edg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
    [Display.cpp]
2025-08-28 Replace status underlines with rectangle borders
    Status Indicator Enhancement:
    - Change underlines to complete rectangle borders around 'HX711' and 'BT' text
    - Add proper spacing so borders don't touch the text (1px top, 2px left/right/bottom)
    - Apply to both status page and main screen Bluetooth indicator
    Rectangle Specifications:
    - HX711: 34x10 rectangle starting at (48,-1) with proper text spacing
    - BT: 16x10 rectangle starting at (108/113,-1) with proper text spacing
    - Rectangles only appear when devices are connected
    - Top line positioned 1 pixel above text, left line 2 pixels before text
    Visual Improvement:
    - Professional rectangular borders instead of simple underlines
    - Clean spaci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
    [Display.cpp]
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2025-08-31 Implement ESP32-S3 SuperMini WiFi antenna fix
    Hardware Issue Solution:
    - Fixes common 'touch antenna to work' problem on SuperMini boards
    - Implements maximum WiFi TX power compensation for poor antenna design
    - Based on proven solution from ESP32 forums (esp32.com/viewtopic.php?t=41895)
    Technical Implementation:
    ✅ Dual-level power boost: Arduino framework (19.5dBm) + ESP-IDF (10dBm)
    ✅ Power settings reapplied after WiFi mode switches (mode change resets power)
    ✅ Configurable enable/disable via ENABLE_SUPERMINI_ANTENNA_FIX define
    ✅ Automatic fallback if ESP-IDF functions unavailable
    ✅ Compatible with BLE coexistence (maintains WiFi sleep mode)
    Code Structure:
    - applySuperMiniAnte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
    [WiFiManager.cpp]
2025-09-01 Remove all emojis from serial monitor output
    Serial Output Cleanup:
    - Removed all Unicode emoji characters from WiFiManager serial messages
    - Replaced emoji prefixes with plain text equivalents
    - Maintained all functionality while improving compatibility
    Changes Applied:
    - setupWiFi(): Cleaned connection status messages
    - maintainWiFi(): Removed emoji status indicators
    - attemptSTAConnection(): Plain text connection feedback
    - switchToAPMode(): Simple AP mode switching messages
    - applySuperMiniAntennaFix(): Clean antenna fix status output
    Benefits:
    - Better compatibility with all serial terminals
    - Cleaner log parsing and automated processing
    - Consistent plain text formatting
    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
    [WiFiManager.cpp, main.cpp]
2025-09-01 Add WiFi and Bluetooth signal strength monitoring
    Signal Strength Features:
    - Real-time WiFi signal strength (RSSI) monitoring in dashboard header
    - Bluetooth signal strength display for connected devices
    - Color-coded indicators (Green/Orange/Red) based on signal quality
    - Signal strength values shown in dBm next to connection icons
    API Enhancements:
    - New /api/signal-strength endpoint for detailed connection info
    - Enhanced dashboard API with signal strength data
    - WiFi connection details (SSID, channel, TX power, IP info)
    - Bluetooth connection status and signal quality
    Web Interface Improvements:
    - Moved signal indicators to header next to battery/BT icons
    - Fixed filter state display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
    [BluetoothScale.cpp, WebServer.cpp, WiFiManager.cpp]
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2025-09-17 Convert from ESP32 BLE Arduino to NimBLE for GaggiMate compatibility
    - Replace ESP32 BLE Arduino library with h2zero/NimBLE-Arduino@^1.4.0
    - Update all BLE includes: BLEDevice -> NimBLEDevice, BLEServer -> NimBLEServer, etc.
    - Convert BLE property constants: BLECharacteristic::PROPERTY_* -> NIMBLE_PROPERTY::*
    - Update callback function signatures to use NimBLE types
    - Update descriptors: BLE2902 -> NimBLE2902
    - This should improve GaggiMate discovery compatibility as both will use same BLE stack
    [BluetoothScale.cpp]
2025-09-17 Convert from BLE Arduino to NimBLE for GaggiMate compatibility
    - Replace ESP32 BLE Arduino with h2zero/NimBLE-Arduino@^1.4.0
    - Update all BLE types: BLEDevice -> NimBLEDevice, BLEServer -> NimBLEServer, etc.
    - Convert BLE property flags to NIMBLE_PROPERTY format
    - Fix descriptor creation for NimBLE (use NimBLEDescriptor instead of NimBLE2902)
    - Update callback function signatures for NimBLE compatibility
    - Should resolve GaggiMate scanning/discovery issues by using same BLE stack
    [BluetoothScale.cpp]
2025-09-17 Fix NimBLE descriptor creation syntax
    - Use createDescriptor() method instead of addDescriptor(new NimBLEDescriptor())
    - Provide correct parameters: UUID, properties, and max length (2 bytes for 2902)
    - Should resolve compilation errors for descriptor creation
    [BluetoothScale.cpp]
2025-09-17 Fix NimBLE boot loop and BLE device name issues
    - Remove manual 0x2902 descriptor creation (NimBLE auto-creates these)
    - Enable scan response and explicitly set advertising name to show full 'WeighMyBru'
    - Resolves boot loop caused by descriptor assertion failure
    - Fixes BLE device name truncation from 'WeighMyB' to full 'WeighMyBru'
    - NimBLE conversion now stable and ready for GaggiMate compatibility testing
    [BluetoothScale.cpp]
2025-09-21 Add filesystem check and user prompt for missing LittleFS
    - Display clear error message when LittleFS.begin() fails
    - Prompt user to run 'pio run -t uploadfs' to upload filesystem
    - Include alternative PlatformIO IDE instructions
    - Explain that scale continues to work but web interface is unavailable
    - Improves user experience by providing clear fix instructions
    [WebServer.cpp]
2025-09-26 fixed status page override wit message
    [Display.cpp]
2025-09-28 Pin ESP32 platform version to 6.12.0 for reproducible builds
    - Lock platform version to espressif32@6.12.0 for build stability
    - Prevents unexpected platform updates breaking production builds
    - Ensures all developers use same platform version
    - Improves CI/CD reliability and build reproducibility
2025-09-28 Add WiFi power management for battery saving
    Features implemented:
    - WiFi on/off toggle functions (enableWiFi, disableWiFi, toggleWiFi)
    - Persistent WiFi enabled state stored in preferences
    - Web interface controls in settings page with live status updates
    - Touch sensor long press (3 seconds) to toggle WiFi
    - Display shows 'WiFi: OFF' when disabled for battery saving
    - API endpoints: /api/wifi-status, /api/wifi-toggle, /api/wifi-enable
    - WiFi setup and maintenance skip when disabled
    - Automatic WiFi mode restoration when re-enabled
    This feature allows users to completely disable WiFi to extend battery life
    when not needed, while preserving saved credentials and easy re-enabling.
    [Display.cpp, TouchSensor.cpp, WebServer.cpp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]
2025-09-28 Fix WiFi disable crash - proper TCP/IP stack cleanup
    Problem: Boot loop when disabling WiFi through web interface caused by
    TCP/IP stack accessing invalid network state after WiFi.mode(WIFI_OFF)
    Solution:
    - Graceful connection cleanup before disabling WiFi
    - Separate handling for STA vs AP mode disconnection
    - Added delay to allow HTTP responses to complete
    - Send response before disabling WiFi to prevent connection loss
    - Proper WiFi.disconnect() and WiFi.softAPdisconnect() sequence
    This prevents the tcpip_api_call error and ensures smooth WiFi power
    management without system crashes.
    [WebServer.cpp, WiFiManager.cpp]
2025-09-28 feat: Complete WiFi power management implementation
    - Add WiFi enable/disable functionality for battery savings
    - Implement long press (5s) tare button for WiFi toggle
    - Add web interface controls for WiFi management
    - Create proper web server lifecycle management
    - Add WiFi status display on OLED ("WiFi: OFF" when disabled)
    - Implement persistent WiFi state storage in preferences
    - Add graceful TCP/IP stack cleanup to prevent boot crashes
    - Clean up dual-button complexity for simpler UX
    - Maintain compatibility with existing tare/status functionality
    New Features:
    - 5-second long press tare button toggles WiFi ON/OFF
    - Web interface "Turn Off WiFi" button (can only turn back on via hardwar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
    [Display.cpp, PowerManager.cpp, TouchSensor.cpp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]
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2025-10-02 fix: Enable WiFi power management globally for consistent battery optimization
    - Move WiFi.setSleep(true) to main.cpp setup() before setupWiFi() call
    - Ensures power management is always active regardless of WiFi state
    - Remove duplicate WiFi.setSleep(true) call from setupWiFi() function
    - Fixes power consumption inconsistency where starting with WiFi OFF used more power than STA→OFF transition
    - Should provide consistent ~80mA baseline power consumption for all WiFi states
    Resolves user-reported issue where WiFi OFF mode consumed 120mA when starting disabled vs 80mA when transitioning from STA to OFF mode.
    [WiFiManager.cpp, main.cpp]
2025-10-02 feat: Add real-time weight and flow rate graph to dashboard
    - Add Chart.js v4.5.0 library (186KB) to data folder for self-hosted serving
    - Replace Flow Rate Graph placeholder with interactive Chart.js canvas
    - Implement dual-axis line chart showing weight (green) and flow rate (blue)
    - Add real-time data updates integrated with existing dashboard polling
    - Chart features:
    - Dual Y-axes: Weight (g) on left, Flow Rate (g/s) on right
    - Time-based X-axis with last 100 data points (10 seconds at 10Hz)
    - Dark theme matching dashboard design
    - Responsive layout optimized for mobile
    - Smooth real-time updates without animation lag
    - Color-coded legend and tooltips
    Perfect for monitoring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
2025-10-02 debug: Add comprehensive chart debugging and error handling
    - Add console logging to track Chart.js initialization
    - Add error handling with try-catch blocks
    - Add fallback initialization attempts with timeouts
    - Add visual error message if chart fails to load
    - Check for Chart.js availability and canvas element existence
    - This will help identify why the chart isn't displaying
2025-10-02 fix: Reduce ESP32 server load to resolve network errors
    - Switch to CDN Chart.js to free up ESP32 memory (remove 186KB file)
    - Reduce update frequency from 5/sec to 1/sec for debugging
    - Disable smart update detection temporarily
    - This should resolve the NetworkError fetch failures by reducing server stress
2025-10-02 fix: Use Chart.js UMD version instead of ES6 module
    - Switch from chart.min.js to chart.umd.js to fix SyntaxError
    - ES6 modules don't work with traditional script tags
    - UMD version provides global Chart constructor for browser use
    - This should resolve the "Chart.js not loaded!" error
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2025-10-02 fix: Expand main container and make graph much larger and faster
    Container Improvements:
    - Main container: 90vw → 95vw (take 95% of screen width)
    - Max width: max-w-4xl → max-w-6xl (much wider on large screens)
    - Graph height: h-80 → h-96 (320px → 384px, 20% taller)
    - Add !important to canvas sizing for forced full size
    Performance Improvements:
    - Update rate: 1000ms → 100ms (1/sec → 10/sec, 10x faster!)
    - Re-enable smart detection for brewing bursts (up to 20/sec)
    - Increase data buffer: 100 → 150 points (15 seconds of history)
    - Status shows 'Real-time Mode: Fast Updates (10/sec)'
    The main container was the bottleneck! Now graph can expand properly. ⚡📊
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

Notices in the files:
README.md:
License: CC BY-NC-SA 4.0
